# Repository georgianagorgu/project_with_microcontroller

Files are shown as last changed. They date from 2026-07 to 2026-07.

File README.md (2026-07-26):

# Embedded Hardware Project

## Overview

This project presents the design and implementation of a custom microcontroller-based embedded system. The hardware was designed from the electronic schematic to the PCB layout using KiCad.

## Features

- Custom PCB design
- LCD display interface
- Temperature sensor
- Buzzer alarm
- Microcontroller-based control

## Hardware Components

- Microcontroller
- LCD display
- Temperature sensor
- Buzzer
- Custom PCB

## Development Tools

- KiCad
- Embedded C
- Git

## Repository Contents

This repository includes:
- Electronic schematic
- PCB layout
- 3D PCB model
- Firmware source code
- Project documentation

## Learning Outcomes

During this project I gained practical experience in:
- Electronic schematic design
- PCB layout design
- Embedded systems development
- Hardware debugging
- Version control using Git and GitHub

## Author

**Georgiana Gorgu**

Faculty of Electronics, Telecommunications and Information Technology  
"Gheorghe Asachi" Technical University of Iași

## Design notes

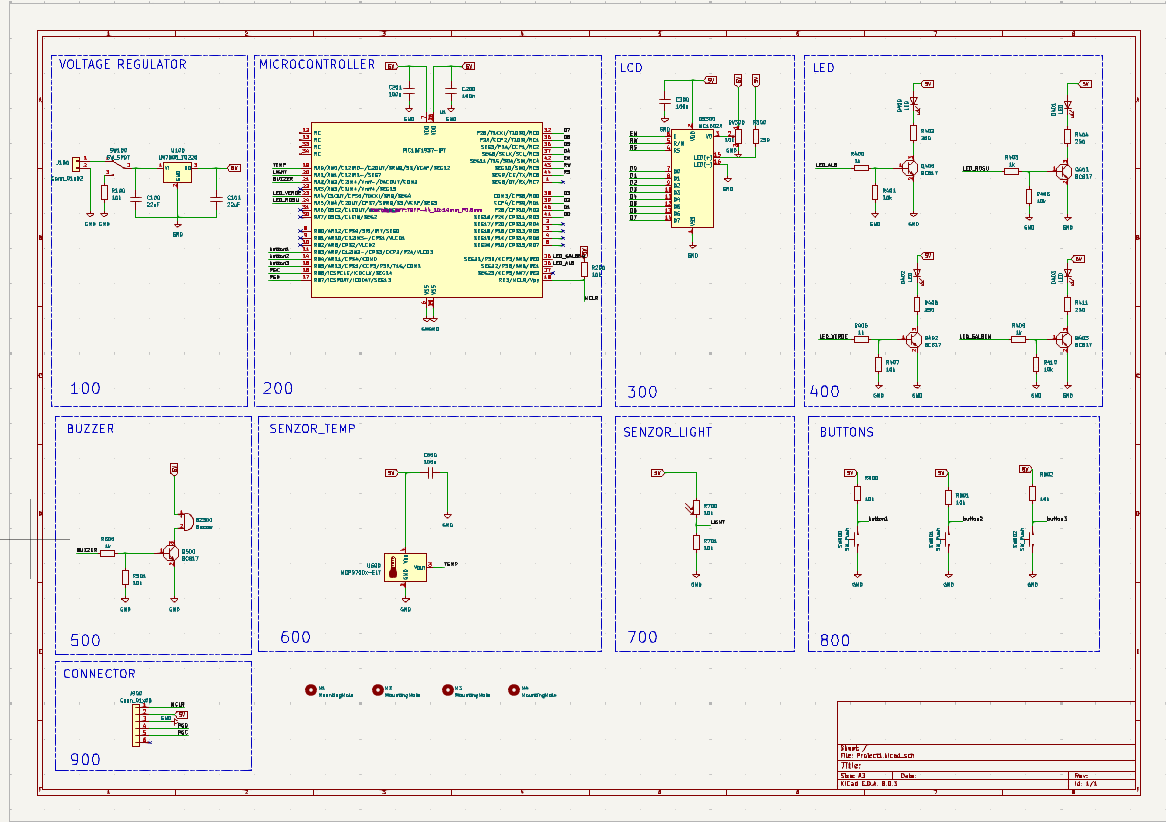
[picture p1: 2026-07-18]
MicrocontrollerProject-main/images/Schematic_image.png

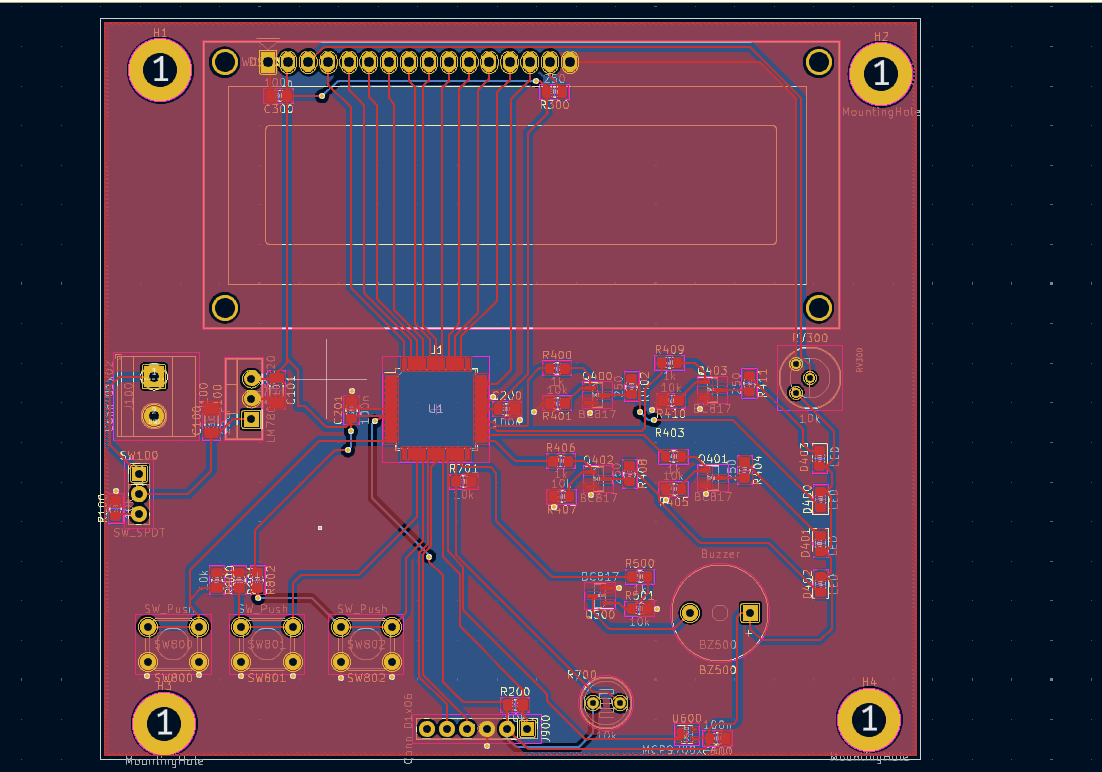
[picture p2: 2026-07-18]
MicrocontrollerProject-main/images/PCB_image.png

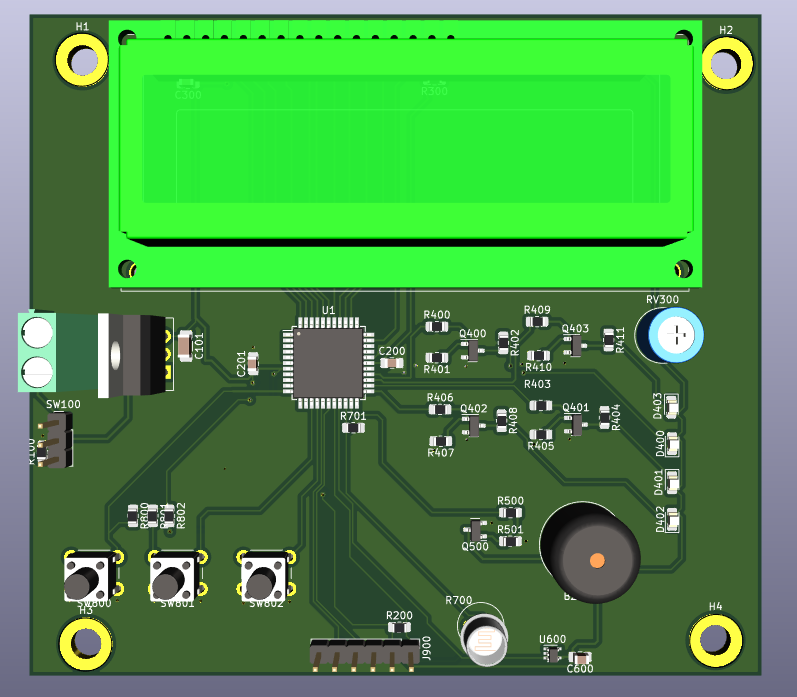
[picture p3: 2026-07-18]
MicrocontrollerProject-main/images/3D_viewer_image.png

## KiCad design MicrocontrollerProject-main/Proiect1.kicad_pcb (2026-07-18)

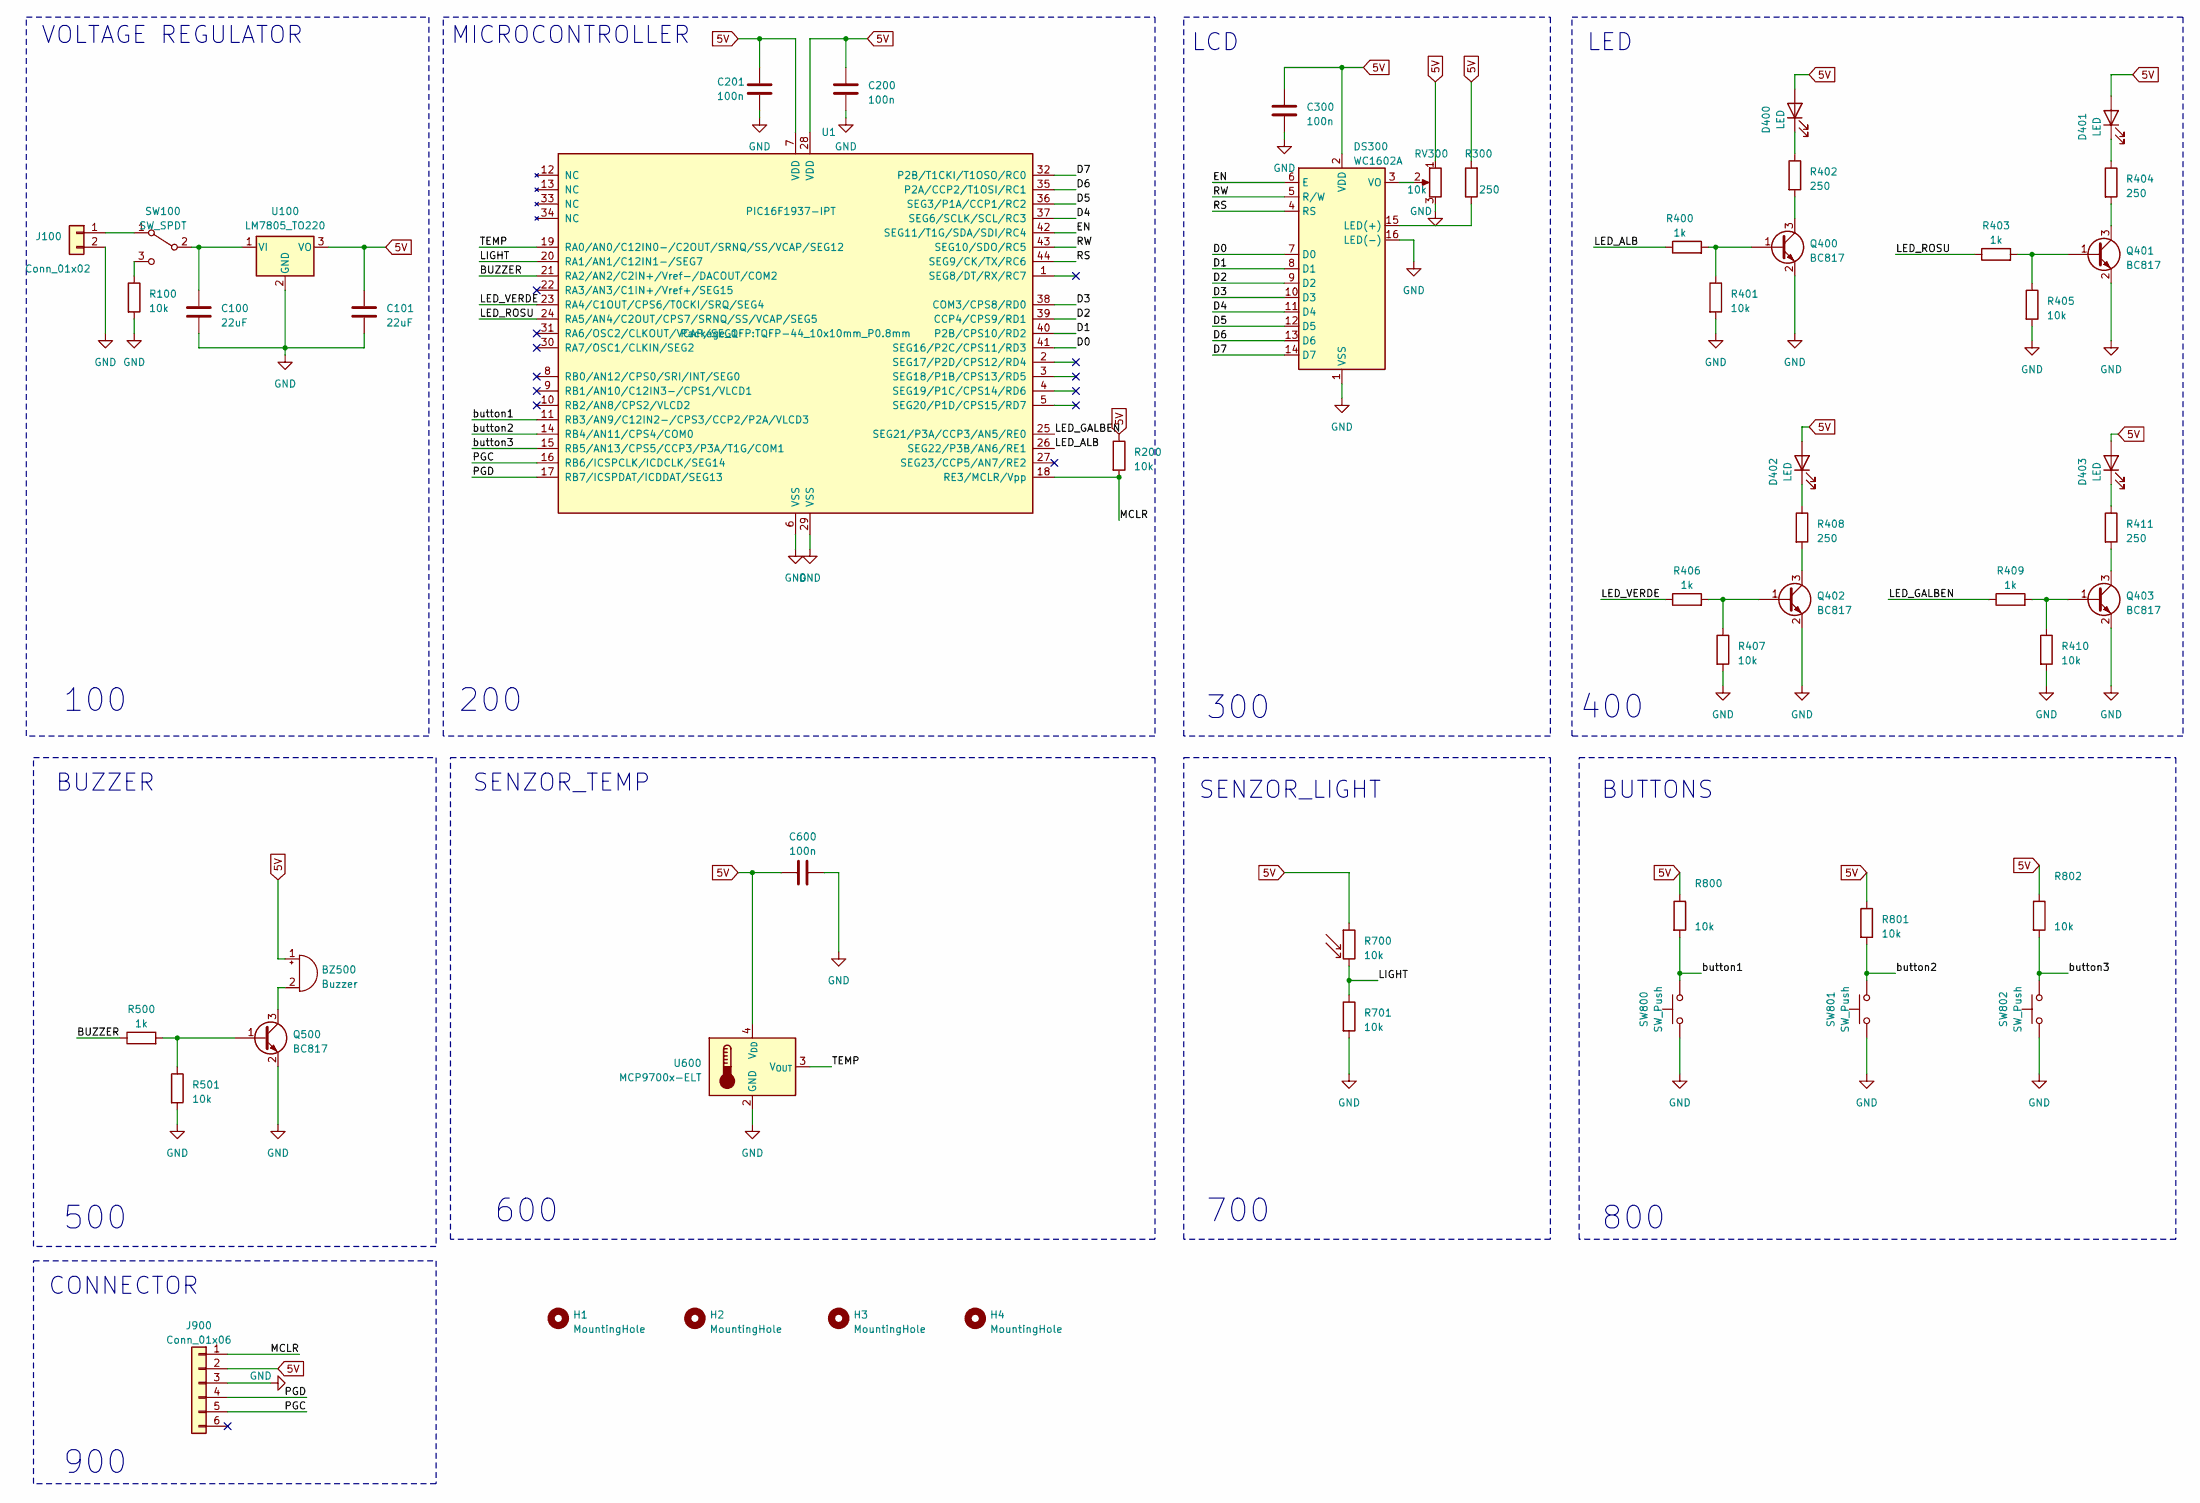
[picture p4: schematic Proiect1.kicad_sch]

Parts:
BZ500: Buzzer; Buzzer_12x9.5RM7.6
C100, C101: 22uF; C_1206_3216Metric_Pad1.33x1.80mm_HandSolder
C200, C201, C300, C600: 100n; C_0805_2012Metric_Pad1.18x1.45mm_HandSolder
D400, D401, D402, D403: LED; LED_0805_2012Metric_Pad1.15x1.40mm_HandSolder
DS300: WC1602A
H1, H2, H3, H4: MountingHole; MountingHole_4.3mm_M4_DIN965_Pad
J100: Conn_01x02; TerminalBlock_Phoenix_MKDS-1,5-2_1x02_P5.00mm_Horizontal
J900: Conn_01x06; PinHeader_1x06_P2.54mm_Vertical
Q400, Q401, Q402, Q403, Q500: BC817; SOT-23
R100, R200, R401, R405, R407, R410, R501, R701, R800, R801, R802: 10k; R_0805_2012Metric_Pad1.20x1.40mm_HandSolder
R300, R402, R404, R408, R411: 250; R_0805_2012Metric_Pad1.20x1.40mm_HandSolder
R400, R403, R406, R409, R500: 1k; R_0805_2012Metric_Pad1.20x1.40mm_HandSolder
R700: 10k; R_LDR_D6.4mm_P3.4mm_Vertical
RV300: 10k; Potentiometer_Bourns_3339H_Vertical
SW100: SW_SPDT; PinHeader_1x03_P2.54mm_Vertical
SW800, SW801, SW802: SW_Push; SW_PUSH_6mm_H7.3mm
U1: PIC16F1937-IPT; TQFP-44_10x10mm_P0.8mm
U100: LM7805_TO220; TO-220-3_Vertical
U600: MCP9700x-ELT; SOT-353_SC-70-5

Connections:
5V: BZ500.1 (-), C101.1, C200.1, C201.1, C300.1, C600.2, D400.2 (A), D401.2 (A), D402.2 (A), D403.2 (A), DS300.2 (VDD), J900.2, R200.1, R300.2, R700.1, R800.1, R801.1, R802.1, RV300.1, U1.7 (VDD), U1.28 (VDD), U100.3 (VO), U600.4 (V_{DD})
/BUZZER: R500.1, U1.21 (RA2/AN2/C2IN+/Vref-/DACOUT/COM2)
/D0: DS300.7 (D0), U1.41 (SEG16/P2C/CPS11/RD3)
/D1: DS300.8 (D1), U1.40 (P2B/CPS10/RD2)
/D2: DS300.9 (D2), U1.39 (CCP4/CPS9/RD1)
/D3: DS300.10 (D3), U1.38 (COM3/CPS8/RD0)
/D4: DS300.11 (D4), U1.37 (SEG6/SCLK/SCL/RC3)
/D5: DS300.12 (D5), U1.36 (SEG3/P1A/CCP1/RC2)
/D6: DS300.13 (D6), U1.35 (P2A/CCP2/T1OSI/RC1)
/D7: DS300.14 (D7), U1.32 (P2B/T1CKI/T1OSO/RC0)
/EN: DS300.6 (E), U1.42 (SEG11/T1G/SDA/SDI/RC4)
/LED_ALB: R400.1, U1.26 (SEG22/P3B/AN6/RE1)
/LED_GALBEN: R409.1, U1.25 (SEG21/P3A/CCP3/AN5/RE0)
/LED_ROSU: R403.1, U1.24 (RA5/AN4/C2OUT/CPS7/SRNQ/SS/VCAP/SEG5)
/LED_VERDE: R406.1, U1.23 (RA4/C1OUT/CPS6/T0CKI/SRQ/SEG4)
/LIGHT: R700.2, R701.1, U1.20 (RA1/AN1/C12IN1-/SEG7)
/MCLR: J900.1, R200.2, U1.18 (RE3/MCLR/Vpp)
/PGC: J900.5, U1.16 (RB6/ICSPCLK/ICDCLK/SEG14)
/PGD: J900.4, U1.17 (RB7/ICSPDAT/ICDDAT/SEG13)
/RS: DS300.4 (RS), U1.44 (SEG9/CK/TX/RC6)
/RW: DS300.5 (R/W), U1.43 (SEG10/SDO/RC5)
/TEMP: U1.19 (RA0/AN0/C12IN0-/C2OUT/SRNQ/SS/VCAP/SEG12), U600.3 (V_{OUT})
/button1: R800.2, SW800.2, U1.11 (RB3/AN9/C12IN2-/CPS3/CCP2/P2A/VLCD3)
/button2: R801.2, SW801.2, U1.14 (RB4/AN11/CPS4/COM0)
/button3: R802.2, SW802.2, U1.15 (RB5/AN13/CPS5/CCP3/P3A/T1G/COM1)
GND: C100.2, C101.2, C200.2, C201.2, C300.2, C600.1, DS300.1 (VSS), DS300.16 (LED(-)), J100.2, J900.3, Q400.2 (E), Q401.2 (E), Q402.2 (E), Q403.2 (E), Q500.2 (E), R100.2, R401.2, R405.2, R407.2, R410.2, R501.2, R701.2, RV300.3, SW800.1, SW801.1, SW802.1, U1.6 (VSS), U1.29 (VSS), U100.2 (GND), U600.2 (GND)
unnamed: BZ500.2 (+), Q500.3 (C)
unnamed: D400.1 (K), R402.1
unnamed: D401.1 (K), R404.1
unnamed: D402.1 (K), R408.1
unnamed: D403.1 (K), R411.1
unnamed: DS300.15 (LED(+)), R300.1
unnamed: DS300.3 (VO), RV300.2
unnamed: J100.1, SW100.1 (A)
unnamed: Q400.1 (B), R400.2, R401.1
unnamed: Q400.3 (C), R402.2
unnamed: Q401.1 (B), R403.2, R405.1
unnamed: Q401.3 (C), R404.2
unnamed: Q402.1 (B), R406.2, R407.1
unnamed: Q402.3 (C), R408.2
unnamed: Q403.1 (B), R409.2, R410.1
unnamed: Q403.3 (C), R411.2
unnamed: Q500.1 (B), R500.2, R501.1
unnamed: C100.1, SW100.2 (B), U100.1 (VI)
unnamed: R100.1, SW100.3 (C)

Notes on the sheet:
100
400
VOLTAGE REGULATOR
700
BUZZER
MICROCONTROLLER
SENZOR_TEMP
SENZOR_LIGHT
CONNECTOR
800
200
900
500
600
BUTTONS
LED
LCD
300

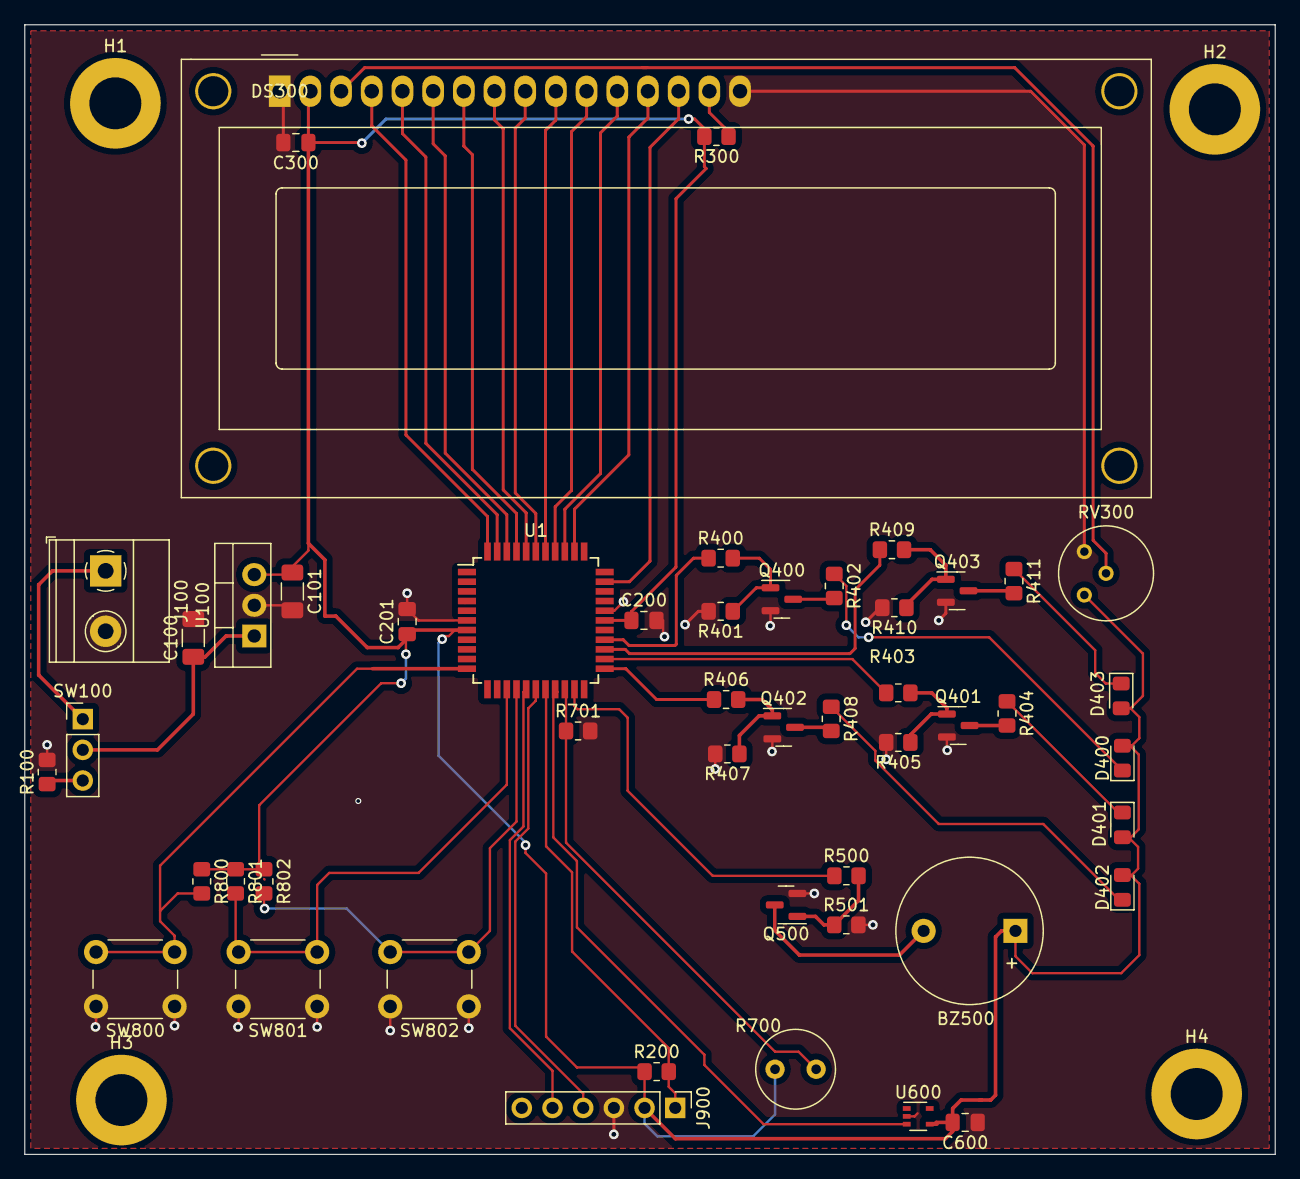
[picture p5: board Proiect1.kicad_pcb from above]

Board: 2 copper layers, 103.5 x 93.5 mm, 53 parts (0 on the bottom side), 45 nets.
